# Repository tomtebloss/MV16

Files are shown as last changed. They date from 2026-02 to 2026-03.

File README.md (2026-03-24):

<h1 align="center">
MV16 smt remake
</h1>

<h2 align="center">
Atari ST MV16 cartridge by Computer's Dream and released by Ubi Soft.<br>
It was included with the game B.A.T. (Bureau of Astral Troubleshooters)
</h2>

---
 
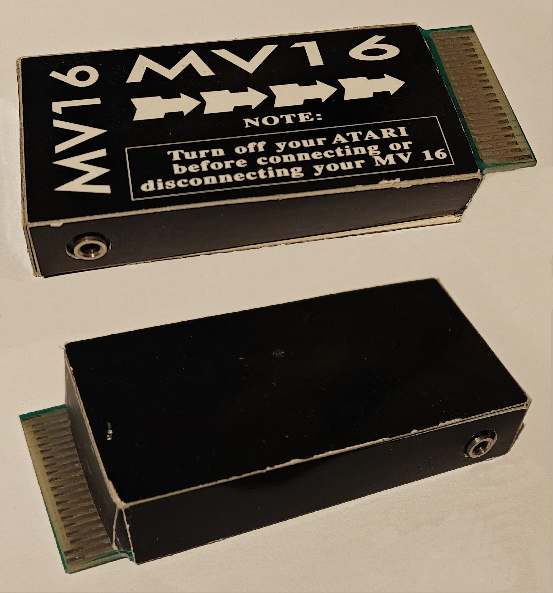
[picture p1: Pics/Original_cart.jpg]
Original MV16 Cartridge
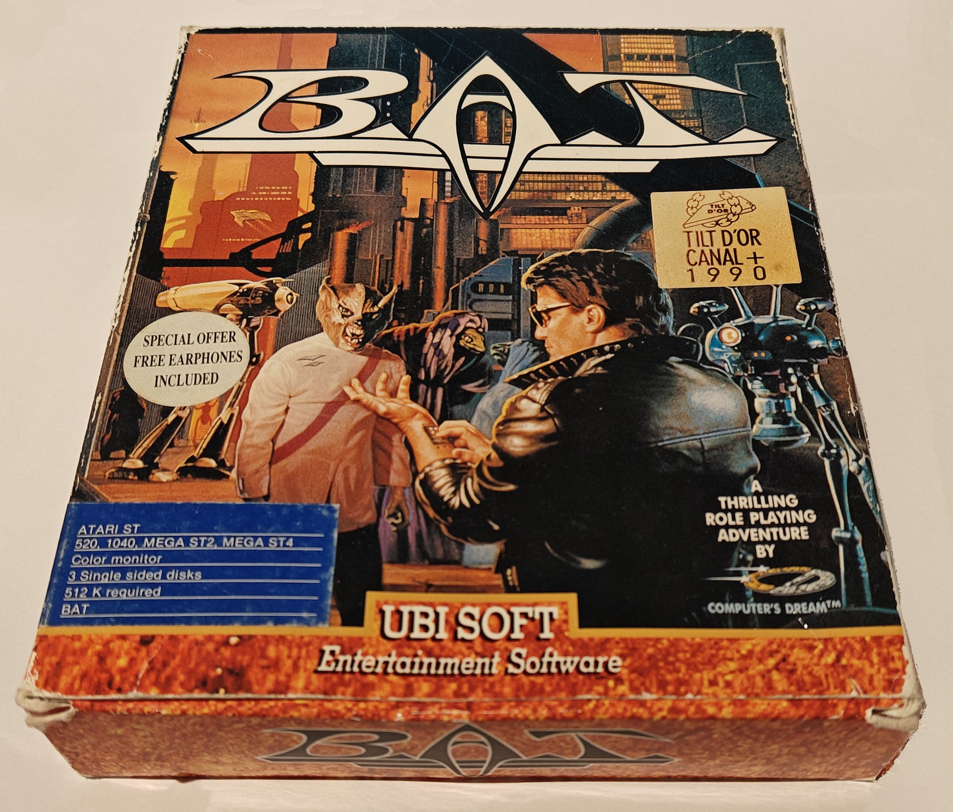
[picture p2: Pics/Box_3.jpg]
Original B.A.T Box
   

---

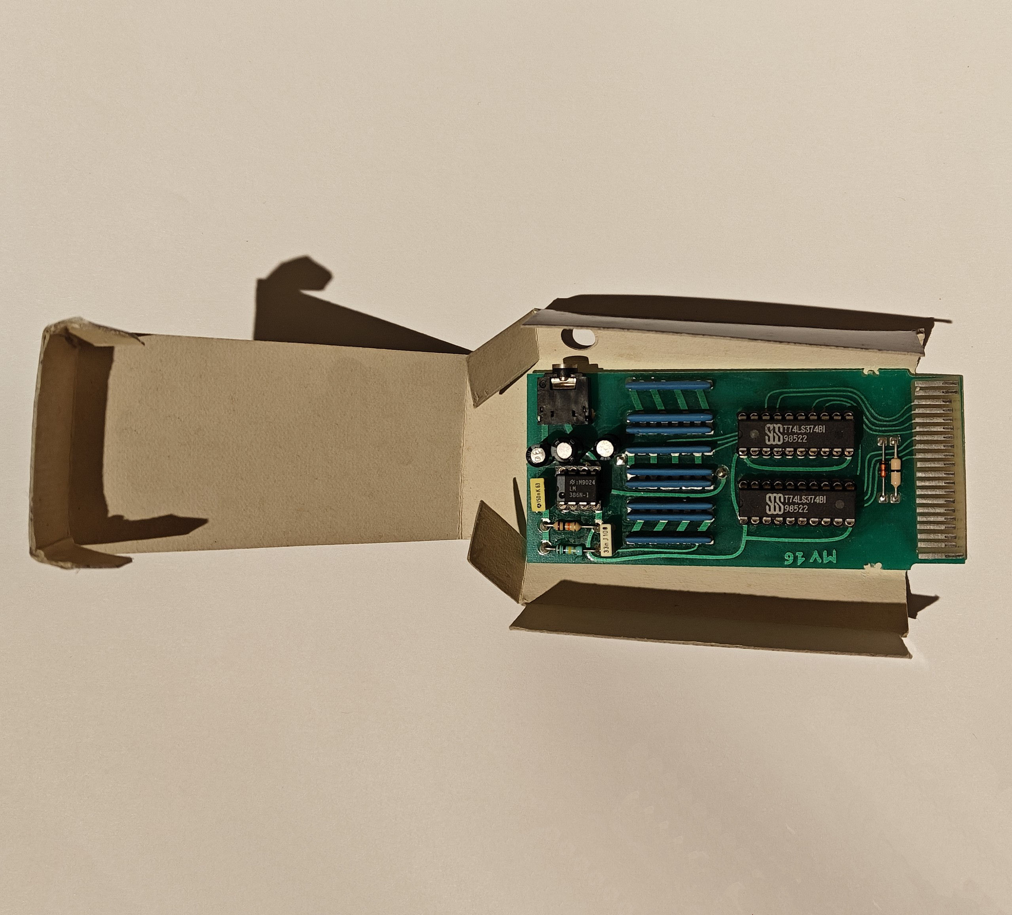
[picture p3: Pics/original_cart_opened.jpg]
Orignal Cartridge opened cardboard box
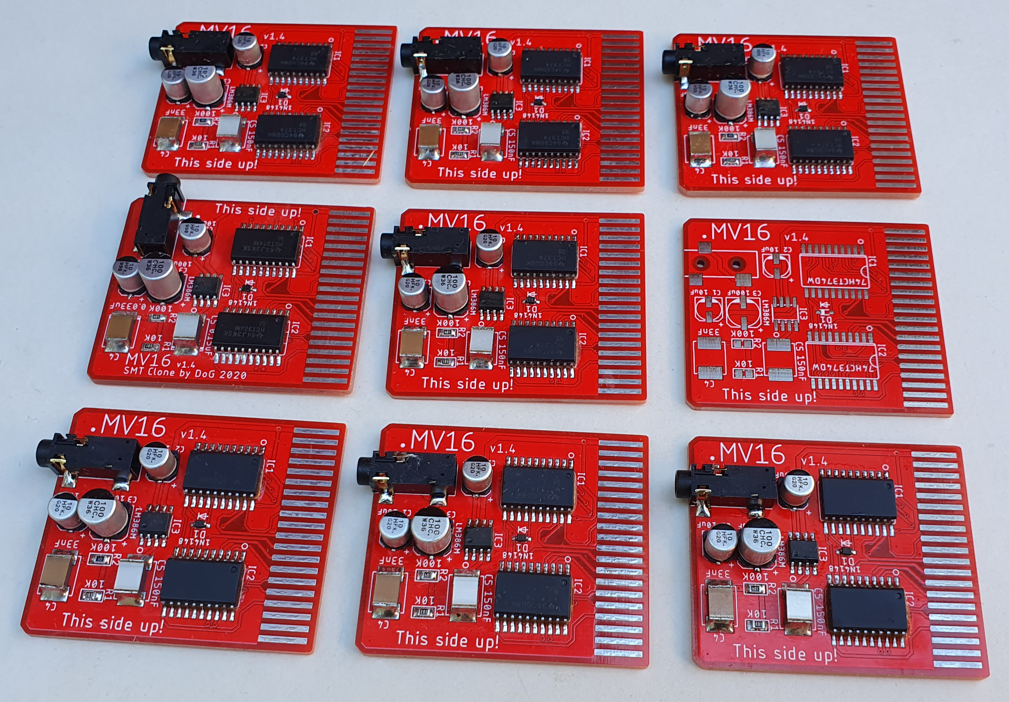
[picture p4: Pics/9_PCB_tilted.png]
Nine versions of MV16 Cartridge
 

---

## Smaller then original  

I bought the original box with cartridge a while ago with the intention to reverse engineer it. The new SMT version was done around summer 2020 (peak covid time) and is more then half as long as the original. The cartridge is a 12 bit resistor ladder with a amplifier chip. Very cheap with cardboard enclosure for the cartridge. The original seem to use very specific capacitor (Polyphenylene Sulfide, Polyethylene Naphthalate?) but I don't know if that is necessary or if it actually is that type of capacitors? Common for audio circuits perhaps? I don't know if can be substituted for normal thin/thick ceramic capacitors instead? The sound is pretty terrible and noisy but better then YM on the ST I guess. Build [Microdeal Stereo Playback](https://github.com/tomtebloss/Microdeal_Stereo_Playback) if you want better sound.

---

## BOM

Bill of material (BOM is included in gerber zip as well as text files in the 'Gerbers' directory)

| Quantity | Parts | Value | Package | Device/Description |
| :--- | :--- | :--- | :--- | :--- |
| 9 | RN1-RN9  | 4.7 kΩ<br>(1% or better) | TC164-FR-074K7L | Array Chip Resistor. Use 1% or better if you can  |
| 1 | R1 | 10 kΩ | R0805 | Resistor, Carbon film |
| 1 | R2 | 100 kΩ | R0805 | Resistor, Carbon film |
| 2 | C1, C2 | 10 µF | UD-5X5,8_NICHICON | Electrolytic Capacitor, 50V on or higher, I used EEE-FK1H100UR |
| 1 | C3 | 100 µF | UD-6,3X7,7_NICHICON | Electrolytic Capacitor, 16V or higher, EEE-1VA101XP |
| 1 | C4 | 33 nF | E/7260-38_NP, 2416  | Film Capacitor, Polyphenylene Sulfide (PPS), <br>Metallized - Stacked, 100V |
| 1 | C5 | 150 nF | E/7260-38_NP, 2416  | Film Capacitor, Polyester, Polyethylene Naphthalate (PEN), <br>Metallized - Stacked, 63V |
| 1 | D1 | 1N4148WT | SOD523 | Schottky barrier diode |
| 1 | J1 | 35RASMT2BHNTRX | 35RASMT2BHNTRX | 3.5mm phone jack, surface mount |
| 2 | IC1, IC2 | 74XX374DW | SOIC-20W | Octal D type transparent LATCH, edge triggered. I used HCT. LS on original|
| 1 | IC3 | LM386M | SOIC-08 | Low Voltage Audio Power Amplifier. I used LM386MX |

---

## Enclosure

<h1 align="center">
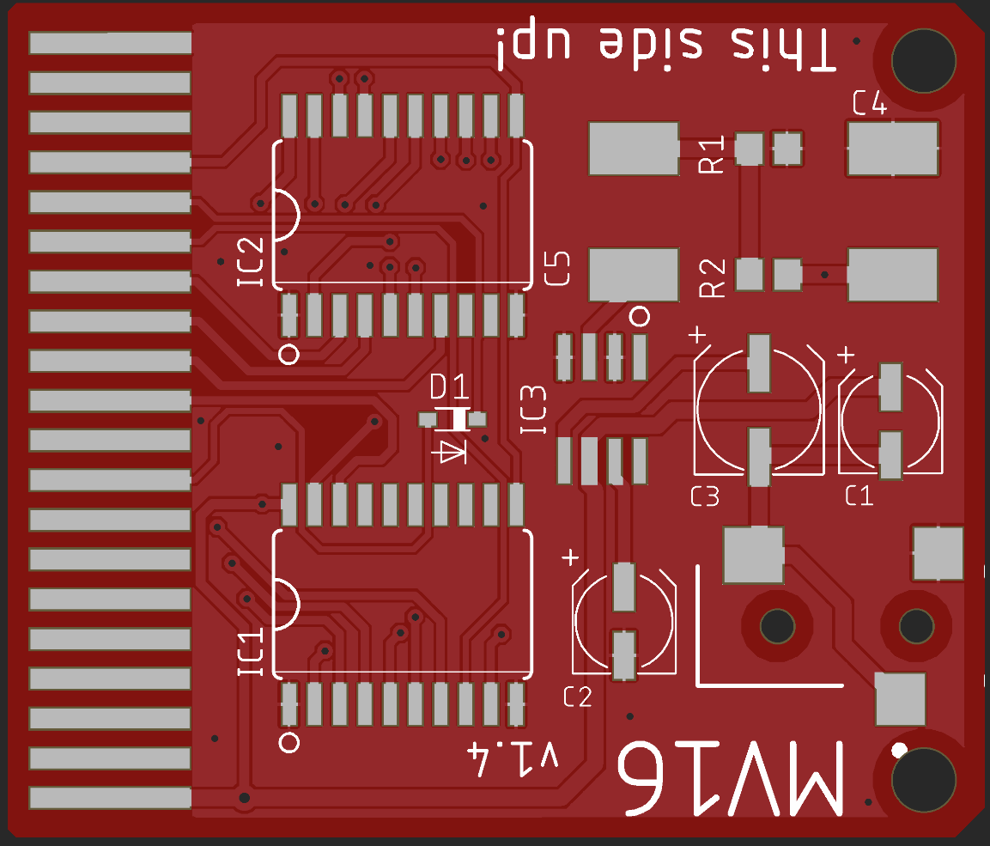
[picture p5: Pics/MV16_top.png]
PCB top side
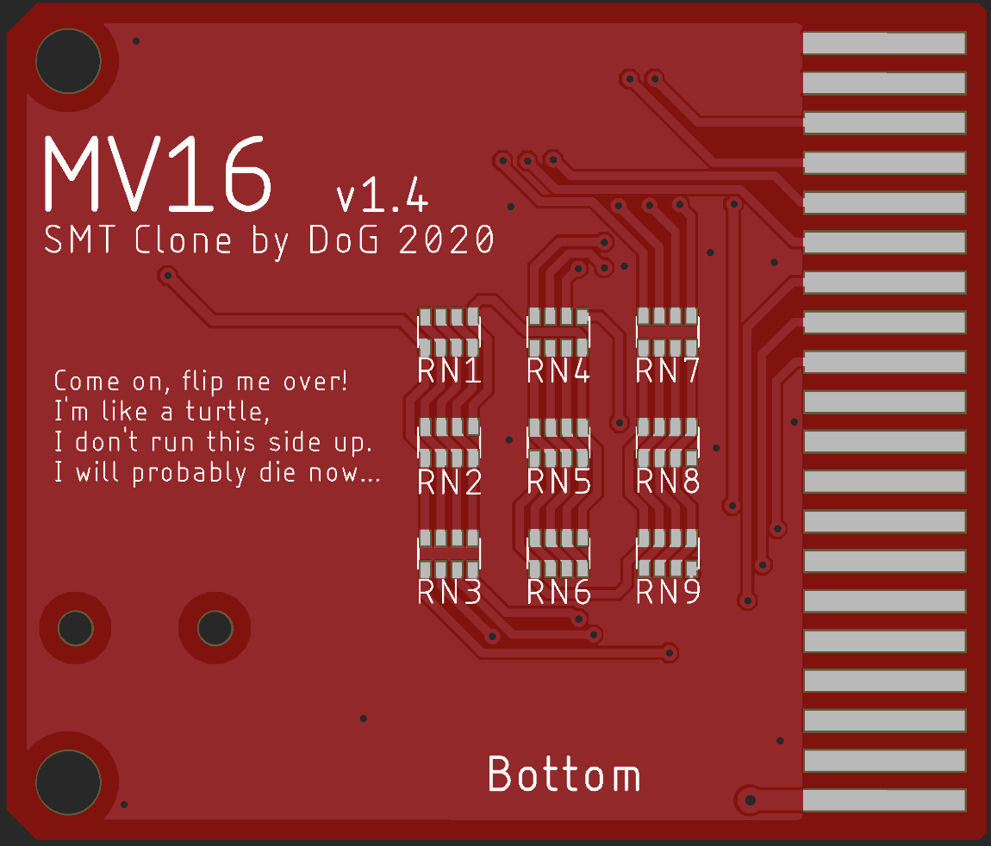
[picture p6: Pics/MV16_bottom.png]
PCB bottom side
                
</h1>

There is no enclosure for this. If anyone makes one, please contact me so I can add it. There is two 3mm holes that has been added on the PCB that can be used for this.

---

## Links and info

I don't know if any cracked version exist of B.A.T that can be used with the cartridge. [Scumm-VM-Lite](https://github.com/agranlund/ScummST) can be used with MV16 <br>
[Built video](https://www.youtube.com/watch?v=QhzbAAYEVPo) by Gadget UK. I [demonstrated the MV16](https://www.youtube.com/watch?v=1RnMYJRYJr0) with Scumm-VM-Lite.<br>
More photos can be found in the [Pics](Pics/) folder. <br>
Datasheet for some of the components used in the new design can be found in the [Datasheet](Datasheet/) folder. <br>
[Original cartridge pics](Pics/MV16_original_PCB_pics.rar) with all the components desoldered from PCB. <br>
[Schematics](Schematics/MV16_v1.4_schematics.pdf) and [gerbers](Gerber/MV16_v1.4_gerber.zip).
Build blog can be found on [Exxos forum](https://www.exxosforum.co.uk/forum/viewtopic.php?t=3005). I do not sell these any more! <br>
Eagle v9.6.2 [board file](Gerber/MV16_v1.4.brd) and [schematics file](Gerber/MV16_v1.4.sch) is also available.

---

## Testing

HexTracker v0.849B and a couple of other mod-trackers can be used with this cartridge. [ScummVM lite](https://www.happydaze.se/scummvm-lite-atari/) (Atari) also works. 

---

PCB routing started by Daniel Guldkrans aka DoG in Eagle around may-june 2020.

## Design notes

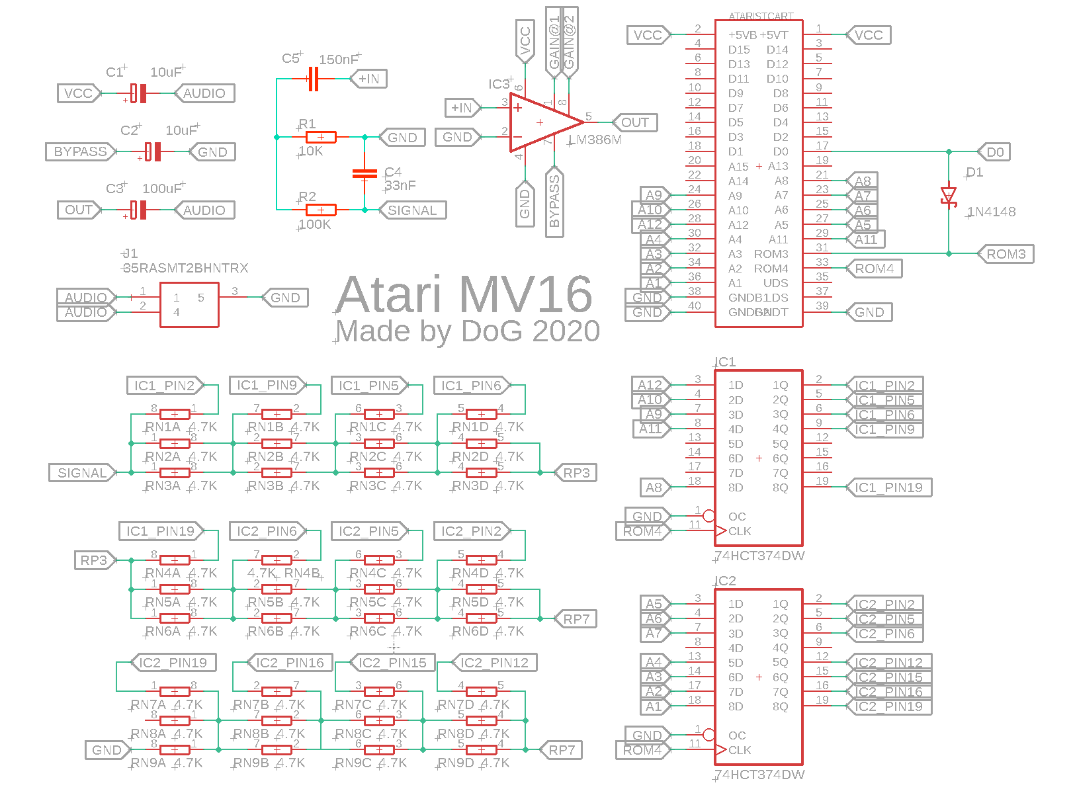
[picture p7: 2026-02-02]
Schematics/MV16_schematics.png

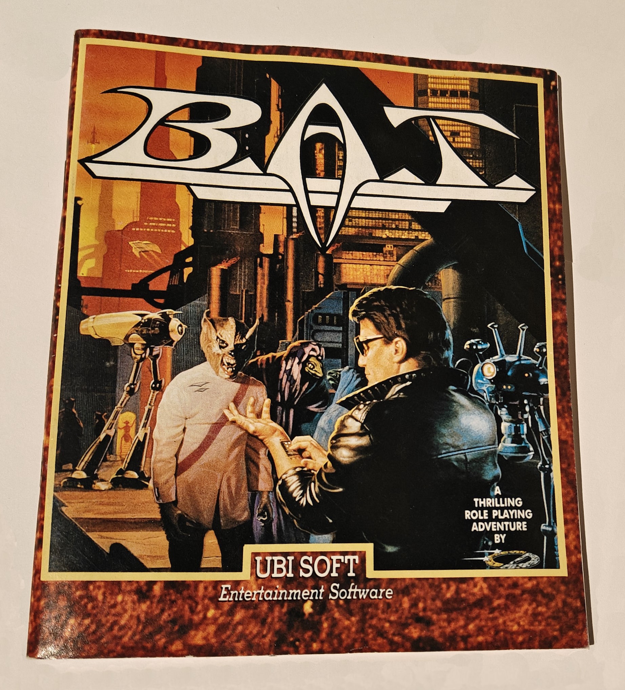
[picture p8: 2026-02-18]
Pics/Story.jpg

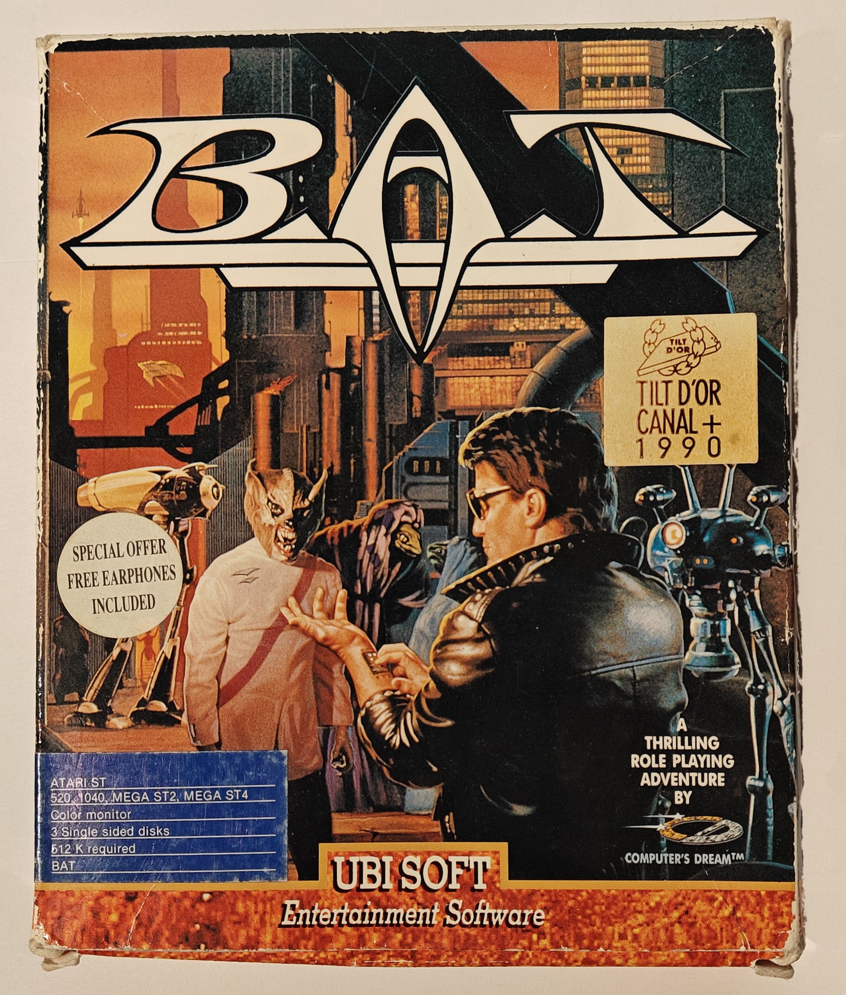
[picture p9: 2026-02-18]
Pics/Box_2.jpg

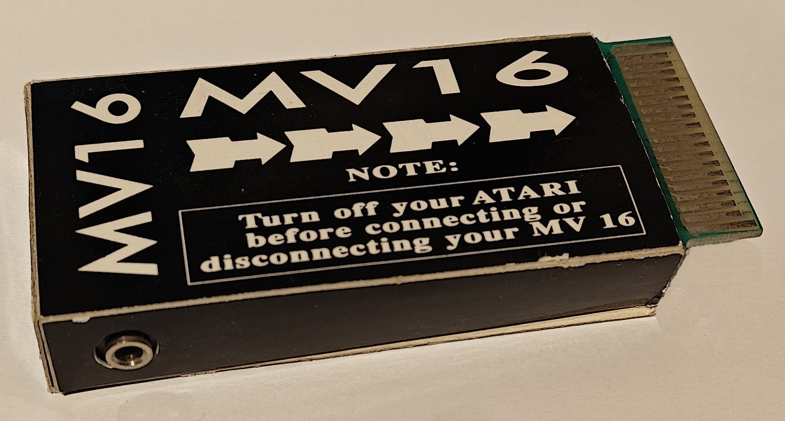
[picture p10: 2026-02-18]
Pics/Original_cart_top.jpg

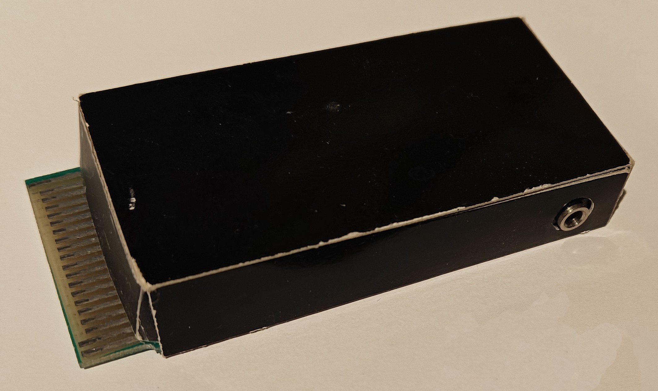
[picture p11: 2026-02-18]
Pics/Original_cart_bottom.jpg

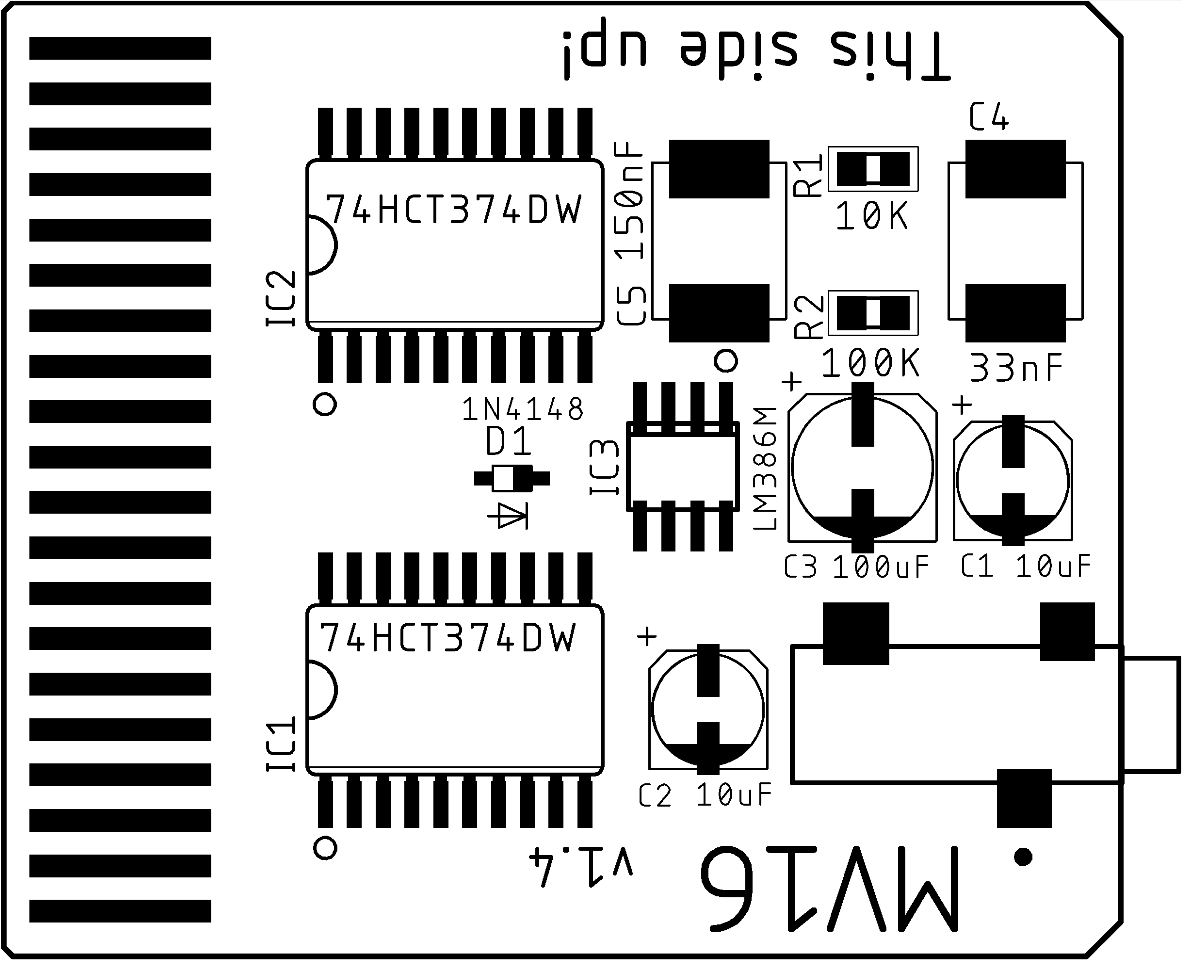
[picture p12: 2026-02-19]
Pics/MV16_layout_top.png

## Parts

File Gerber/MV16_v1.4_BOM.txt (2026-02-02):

MV16 v1.4 BOM

Qty Value               Device              Package             Parts                                       Description                                    ALLIED_NUMBER ALLIED_PRICE-STOCK                                              DESCRIPTION                     HEIGHT MANUFACTURER_NAME MANUFACTURER_PART_NUMBER MF MOUSER_PART_NUMBER MOUSER_PRICE-STOCK                                                                                MPN OC_FARNELL OC_NEWARK POPULARITY RS_PART_NUMBER RS_PRICE-STOCK SPICEPREFIX
1   0.033uF             CPOL-USE/7260-38R   E/7260-38R          C4                                          POLARIZED CAPACITOR, American symbol                                                                                                                                                                                                                                                                                                                            1                                        C          
1   0.15uF              CPOL-USE/7260-38R   E/7260-38R          C5                                          POLARIZED CAPACITOR, American symbol                                                                                                                                                                                                                                                                                                                            1                                        C          
1   100uF               CPOL-EUUD-6,3X7,7   UD-6,3X7,7_NICHICON C3                                          POLARIZED CAPACITOR, European symbol                                                                                                                                                                                                                                                                                                                            1                                        C          
2   10uF                CPOL-EUUD-5X5,8     UD-5X5,8_NICHICON   C1, C2                                      POLARIZED CAPACITOR, European symbol                                                                                                                                                                                                                                                                                                                            0                                        C          
1   10K                 R-EU_R0805          R0805               R1                                          RESISTOR, European symbol                                                                                                                                                                                                                                                                                                                                       86                                       R          
1   100K                R-EU_R0805          R0805               R2                                          RESISTOR, European symbol                                                                                                                                                                                                                                                                                                                                       86                                       R          
1   1N4148              1N4148              SOD323_ST           D1                                          Schottky barrier diode                                                                                                                                                                                                                                                                                                                                          7                                                   
1   35RASMT2BHNTRX      35RASMT2BHNTRX      35RASMT2BHNTRX_1    J1                                          3.5mm phone jack, surface mount                70930061      https://www.alliedelec.com/switchcraft-35rasmt2bhntrx/70930061/ 3.5mm phone jack, surface mount mm     Switchcraft       35RASMT2BHNTRX              502-35RASMT2BHNTRX https://www.mouser.co.uk/ProductDetail/Switchcraft/35RASMT2BHNTRX?qs=iwvYsH9bSFaJ2uZlz7DW5A%3D%3D                                                                              
9   4.7K 1%             4R-NEXBV8V          EXBV8V              RN1, RN2, RN3, RN4, RN5, RN6, RN7, RN8, RN9 Array Chip Resistor                                                                                                                                                                                                                                                                                                                        unknown    unknown   0                                                   
2   74HCT374DW          74HCT374DW          SO20W               IC1, IC2                                    Octal D type transparent LATCH, edge triggered                                                                                                                                                                                                                                                                                                                  0                                                   
1   LM386M              LM386M-1            SO08                IC3                                         Low Voltage Audio Power Amplifier                                                                                                                                                                                                                                                                                                                               0

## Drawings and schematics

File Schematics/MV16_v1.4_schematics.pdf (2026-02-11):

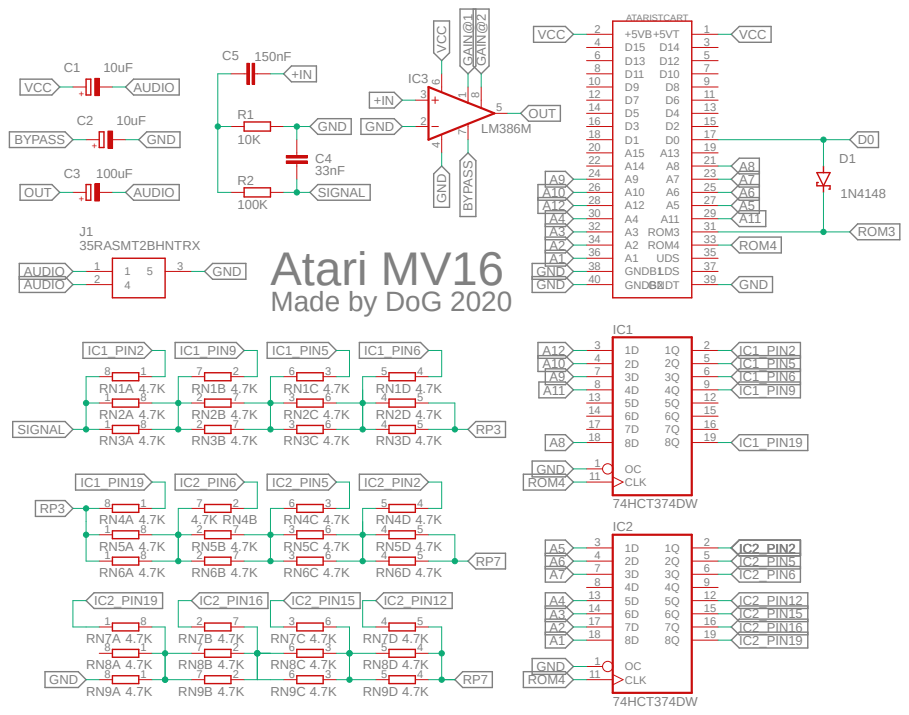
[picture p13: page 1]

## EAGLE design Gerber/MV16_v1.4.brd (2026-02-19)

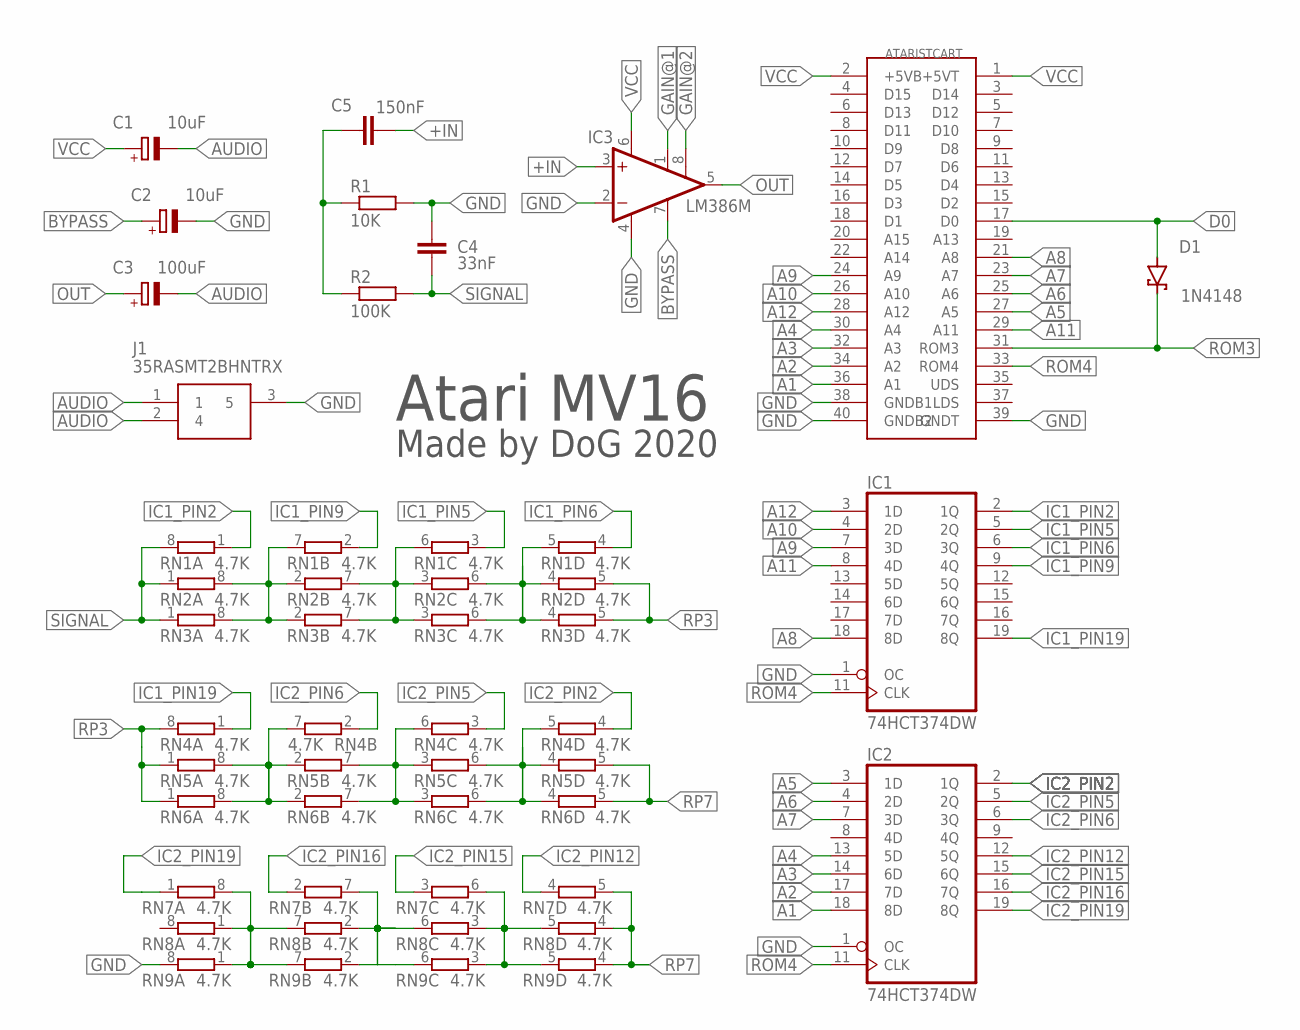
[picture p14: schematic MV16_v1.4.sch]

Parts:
C1, C2: 10uF; UD-5X5,8_NICHICON
C3: 100uF; UD-6,3X7,7_NICHICON
C4: 33nF; E/7260-38_NP
C5: 150nF; E/7260-38_NP
D1: 1N4148; SOD323_ST
IC1, IC2: 74HCT374DW; SO20W
IC3: LM386M; SO08
J1: 35RASMT2BHNTRX; 35RASMT2BHNTRX_1
P1: ATARI_ST_CART_FIXED; ATARI_ST_CART
R1: 10K; R0805
R2: 100K; R0805
RN1, RN2, RN3, RN4, RN5, RN6, RN7, RN8, RN9: 4.7K; EXBV8V

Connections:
+IN: C5.- (2), IC3.3 (+IN)
A1: IC2.18 (8D), P1.36 (A1)
A2: IC2.17 (7D), P1.34 (A2)
A3: IC2.14 (6D), P1.32 (A3)
A4: IC2.13 (5D), P1.30 (A4)
A5: IC2.3 (1D), P1.27 (A5)
A6: IC2.4 (2D), P1.25 (A6)
A7: IC2.7 (3D), P1.23 (A7)
A8: IC1.18 (8D), P1.21 (A8)
A9: IC1.7 (3D), P1.24 (A9)
A10: IC1.4 (2D), P1.26 (A10)
A11: IC1.8 (4D), P1.29 (A11)
A12: IC1.3 (1D), P1.28 (A12)
AUDIO: C1.-, C3.-, J1.1, J1.2 (4)
BYPASS: C2.+, IC3.7 (BYPASS)
D0: D1.A, P1.17 (D0)
GAIN@1: IC3.1 (GAIN)
GAIN@2: IC3.8 (GAIN)
GND: C2.-, C4.- (2), IC1.1 (OC), IC1.10 (GND), IC2.1 (OC), IC2.10 (GND), IC3.2 (-IN), IC3.4 (GND), J1.3 (5), P1.38 (GNDB1), P1.39 (GNDT), P1.40 (GNDB2), R1.2, RN9.8 (2)
IC1_PIN2: IC1.2 (1Q), RN1.1
IC1_PIN5: IC1.5 (2Q), RN1.3 (1)
IC1_PIN6: IC1.6 (3Q), RN1.4 (1)
IC1_PIN9: IC1.9 (4Q), RN1.2 (1)
IC1_PIN19: IC1.19 (8Q), RN4.1
IC2_PIN2: IC2.2 (1Q), RN4.4 (1)
IC2_PIN5: IC2.5 (2Q), RN4.3 (1)
IC2_PIN6: IC2.6 (3Q), RN4.2 (1)
IC2_PIN12: IC2.12 (5Q), RN7.4 (1)
IC2_PIN15: IC2.15 (6Q), RN7.3 (1)
IC2_PIN16: IC2.16 (7Q), RN7.2 (1)
IC2_PIN19: IC2.19 (8Q), RN7.1
unnamed: C5.+ (1), R1.1, R2.1
unnamed: RN4.7 (2), RN5.2 (1), RN5.8 (2), RN6.2 (1), RN6.8 (2)
unnamed: RN4.6 (2), RN5.3 (1), RN5.7 (2), RN6.3 (1), RN6.7 (2)
unnamed: RN4.5 (2), RN5.4 (1), RN5.6 (2), RN6.4 (1), RN6.6 (2)
unnamed: RN1.7 (2), RN2.2 (1), RN2.8 (2), RN3.2 (1), RN3.8 (2)
unnamed: RN1.6 (2), RN2.3 (1), RN2.7 (2), RN3.3 (1), RN3.7 (2)
unnamed: RN1.5 (2), RN2.4 (1), RN2.6 (2), RN3.4 (1), RN3.6 (2)
unnamed: RN7.8 (2), RN8.1, RN8.7 (2), RN9.1, RN9.7 (2)
unnamed: RN7.7 (2), RN8.2 (1), RN8.6 (2), RN9.2 (1), RN9.6 (2)
unnamed: RN7.6 (2), RN8.3 (1), RN8.5 (2), RN9.3 (1), RN9.5 (2)
OUT: C3.+, IC3.5 (OUT)
ROM3: D1.C, P1.31 (ROM3)
ROM4: IC1.11 (CLK), IC2.11 (CLK), P1.33 (ROM4)
RP3: RN2.5 (2), RN3.5 (2), RN4.8 (2), RN5.1, RN6.1
RP7: RN5.5 (2), RN6.5 (2), RN7.5 (2), RN8.4 (1), RN9.4 (1)
SIGNAL: C4.+ (1), R2.2, RN1.8 (2), RN2.1, RN3.1
VCC: C1.+, IC1.20 (VCC), IC2.20 (VCC), IC3.6 (VS), P1.1 (+5VT), P1.2 (+5VB)

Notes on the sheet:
Atari MV16
Made by DoG 2020

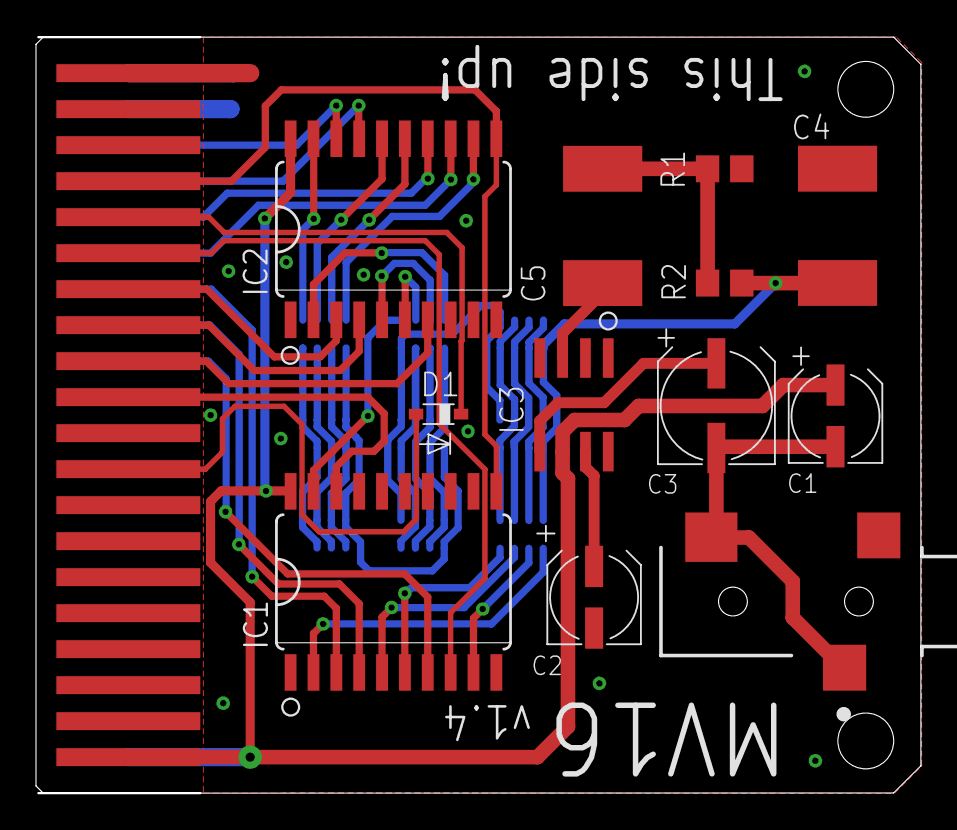
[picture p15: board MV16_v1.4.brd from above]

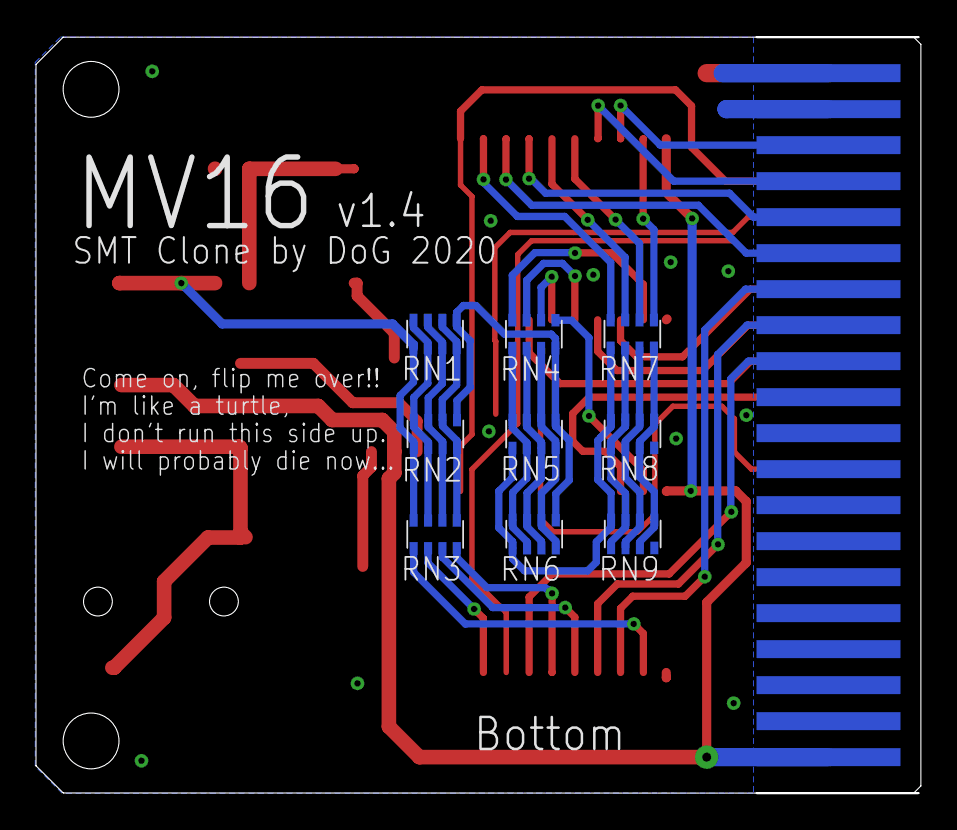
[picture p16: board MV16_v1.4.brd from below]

Board: 2 copper layers, 49.2 x 42.0 mm, 22 parts (9 on the bottom side), 46 nets.

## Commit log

2026-02-02 Gerber and BOM
2026-02-02 Top, bottom and schematics exported from EAGLE
2026-02-02 Pics of original cartridge PCB
2026-02-02 Pics of 5 soldered MV16
2026-02-02 Pics of 9 soldered and unsoldered MV16
2026-02-11 Moved to /Schematics folder
2026-02-18 Revise BOM format and update component details
    Updated the Bill of Materials (BOM) section to include parts and improved descriptions.
2026-02-19 New gerber with holes
2026-02-19 Fix image attributes and enclosure section in README
    Updated image alignment and sizes in README.
2026-02-19 Revise capacitor entries in the components table
    Updated capacitor descriptions for clarity and formatting.
2026-02-19 EAGLE v9.6.2 files
    [MV16_v1.4.brd, MV16_v1.4.sch]
2026-02-19 Fix wording in BOM section of README
2026-02-19 Add Eagle board and schematics file links
    Added links to Eagle board and schematics files.
